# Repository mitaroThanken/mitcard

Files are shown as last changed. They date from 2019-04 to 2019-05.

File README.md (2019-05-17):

# mitcard

自作キーボードの習作。

## 特徴

* [Teency LC](https://www.pjrc.com/teensy/teensyLC.html)/[Teency 3.2](https://www.pjrc.com/teensy/teensy31.html)両対応
* 2x2のキーマトリックス
* [スイッチ用PCBソケット](https://yushakobo.jp/shop/a01ps/)使用
* 2つのタッチキー
* [modulo](http://biacco42.hatenablog.com/entry/2018/12/13/063814) 互換のジャック (※1)
* [SparkFun TeencyView](https://www.sparkfun.com/products/14048) 搭載可能 (※2)
* その他I/Oピンを外出し (※2)

※1 ソフトウェアは未対応、また、Teency LCは5Vトレラントではないことに注意。
※2 一部ピンが重複しています。

## 基板以外の材料

### 必須

* [Teency LC](https://www.pjrc.com/teensy/teensyLC.html)、または、[Teency 3.2](https://www.pjrc.com/teensy/teensy31.html)
  どちらかを用意してください。Modulo Pendant 互換を目指す場合は[Teency 3.2](https://www.pjrc.com/teensy/teensy31.html)一択です。
* ピンヘッダ・ピンソケット
  ボード内側のピンは使用していません。ですので、ボードの縁にあるスルーホールの数に対応したピンヘッダ・ピンソケットを用意してください。
  [スイッチサイエンス取扱のSparkFun製のもの](https://www.switch-science.com/catalog/2851/)とピンソケットでもよいです。

## メカニカルキーボードにするのに必須

以下のものをそれぞれ4つ用意してください。

* [スイッチ用PCBソケット](https://yushakobo.jp/shop/a01ps/)使用
* キースイッチ
  MX互換とKailh Chocに対応します。お好きなものをどうぞ。

## Modulo Pendant 互換品にするのに必須

以下のものをそれぞれ2つ用意してください。

* [MJ-4PP-9](http://akizukidenshi.com/catalog/g/gC-06070/)
* 抵抗
  (抵抗の大きさについては現在検討中。)

## OLED をつける場合

[SparkFun TeencyView](https://www.sparkfun.com/products/14048)が使用可能です。

ただし、D/Cを5ピンから21ピンに変更する必要があります。[ここ](https://learn.sparkfun.com/tutorials/teensyview-hookup-guide)を参考にデフォルトのラインを切って、21ピンの方にハンダでつなげてください。

(以降、更新予定)

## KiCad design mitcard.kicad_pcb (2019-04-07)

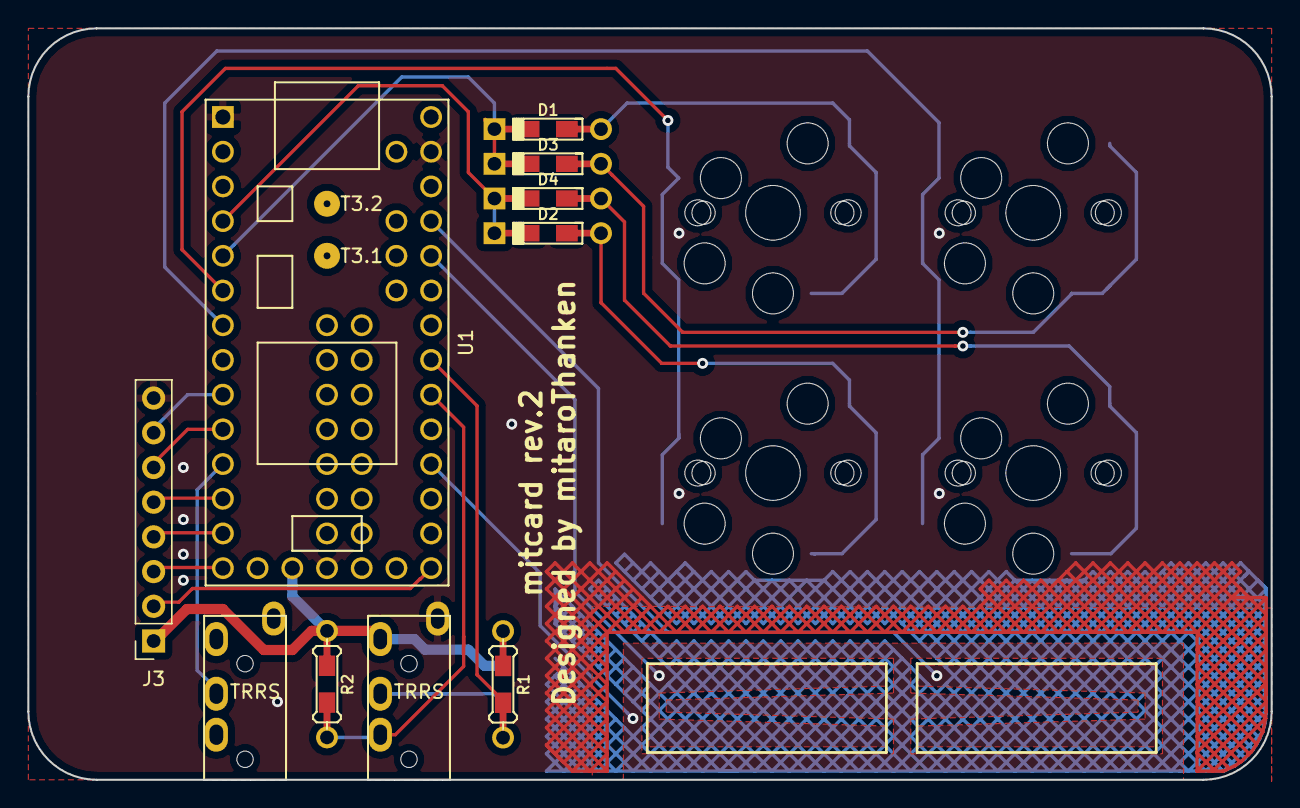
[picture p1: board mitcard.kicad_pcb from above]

Board: 2 copper layers, 91.0 x 55.0 mm, 14 parts (0 on the bottom side), 19 nets.

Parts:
D1, D2, D3, D4: D; Diode-dual
J1, J2: MJ-4PP-9; MJ-4PP-9_1side
J3: Conn_01x08; PinSocket_1x08_P2.54mm_Vertical
R1, R2: 4.7K; Resistor-Hybrid
SW1, SW2, SW3, SW4: SW_PUSH; CherryMX_Choc_Hotswap_1side
U1: Teensy-LC; Teensy30_31_32_LC

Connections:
/3.3V: J1.D, J3.1, R1.1, R2.1, U1.16
/INT: J2.C, U1.11
/SCL: J1.C, R1.2, U1.26
/SDA: J1.B, R2.2, U1.25
/col1row0: D3.2, SW3.2
CS: J3.5, U1.12
GND: J1.A, J3.8, U1.1, U1.17, U1.32
MISO: J3.3, U1.14
MOSI: J3.4, U1.13
unnamed: D1.2, SW1.2
unnamed: D2.2, SW2.2
unnamed: D4.2, SW4.2
RX: J3.7, U1.9
SCK: J3.2, U1.20
TX: J3.6, U1.10
col0: SW1.1, SW2.1, U1.6
col1: SW3.1, SW4.1, U1.7
row0: D1.1, D3.1, U1.5
row1: D2.1, D4.1, U1.4

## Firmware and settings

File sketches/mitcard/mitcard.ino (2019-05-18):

#include <TeensyView.h>
#include <Keyboard.h>
#include <Bounce2.h>

// for Keyswiches
const int ROW_NUM = 2;
const int COL_NUM = 2;
const int ROW_PIN[ROW_NUM] = { 3, 2 };
const int COL_PIN[COL_NUM] = { 4, 5 };

Bounce * debounce[ROW_NUM] = { new Bounce[COL_NUM], new Bounce[COL_NUM] };

const int KEY_MAP[ROW_NUM][COL_NUM] = {
  { KEY_A, KEY_B },
  { KEY_1, KEY_2 }
};

const String KEY_TITLE[ROW_NUM][COL_NUM] = {
  { "A?", "B!" },
  { "1.", "2.." }
};

// for Touch
const int TOUCH_B_PIN = 16;
const int TOUCH_L_PIN = 22;
const int TOUCH_R_PIN = 23;
const int TOUCH_DIFF = 500;

int touchB_avg = 0;
int touchR_avg = 0;
int touchL_avg = 0;
int touchB_th = 0;
int touchR_th = 0;
int touchL_th = 0;
bool touchB_touched = false;
bool touchL_touched = false;
bool touchR_touched = false;

void renew_touch_avg() {
  int t = touchRead(TOUCH_B_PIN);
  touchB_avg = (touchB_avg >> 1) + (touchB_avg >> 2) + (t >> 2);
  t = touchRead(TOUCH_L_PIN);
  touchL_avg = (touchL_avg >> 1) + (touchL_avg >> 2) + (t >> 2);
  t = touchRead(TOUCH_R_PIN);
  touchR_avg = (touchR_avg >> 1) + (touchR_avg >> 2) + (t >> 2);
}

// for LED
const int LED_PIN = 13;
int ledState = LOW;

// for TeensyView
// cf. https://learn.sparkfun.com/tutorials/teensyview-hookup-guide
#define PIN_RESET 15
#define PIN_DC    21
#define PIN_CS    10
#define PIN_SCK   13
#define PIN_MOSI  11

TeensyView oled(PIN_RESET, PIN_DC, PIN_CS, PIN_SCK, PIN_MOSI);
elapsedMillis sincePrint;

const String MY_NAME = "mitarothanken";
const String THIS_CARD = "mitcard!";

// Center and print a small title
// This function is quick and dirty. Only works for titles one
// line long.
void printTitle(String title, int font)
{
  int middleX = oled.getLCDWidth() / 2;
  int middleY = oled.getLCDHeight() / 2;

  oled.clear(PAGE);
  oled.setFontType(font);
  // Try to set the cursor in the middle of the screen
  oled.setCursor(middleX - (oled.getFontWidth() * (title.length() / 2)),
                 middleY - (oled.getFontWidth() / 2));
  // Print the title:
  oled.print(title);
  oled.display();
  //delay(1500);
  //oled.clear(PAGE);
  sincePrint = 0;
}

void setup(void) {
  // LED
  pinMode(LED_PIN, OUTPUT);
  digitalWrite(LED_PIN, ledState);

  // TeencyView (splash screen)
  oled.begin();
  oled.clear(ALL);
  oled.display();

  // Keyswitches (matrix)
  for (int row = 0; row < ROW_NUM; row++) {
    pinMode(ROW_PIN[row], OUTPUT);
  }

  for (int col = 0; col < COL_NUM; col++) {
    pinMode(COL_PIN[col], INPUT_PULLUP);
  }

  for (int row = 0; row < ROW_NUM; row++) {
    for (int col = 0; col < COL_NUM; col++) {
      debounce[row][col].attach(COL_PIN[col]);
      debounce[row][col].interval(25);
    }
    digitalWrite(ROW_PIN[row], HIGH);
  }

  // Touch (init)
  int i = 0;
  int t = 0;
  for (; i < 4; i++) {
    t = touchRead(TOUCH_B_PIN);
    touchB_avg += (t >> 2);
    t = touchRead(TOUCH_L_PIN);
    touchL_avg += (t >> 2);
    t = touchRead(TOUCH_R_PIN);
    touchR_avg += (t >> 2);
  }
  for (; i < 100; i++) {
    renew_touch_avg();
  }

  // FIXME TOUCH_DIFF
  touchB_th = touchB_avg + (TOUCH_DIFF >> 2);
  touchL_th = touchL_avg + TOUCH_DIFF;
  touchR_th = touchR_avg + TOUCH_DIFF;

  // Random seed.
  randomSeed(A0);

  // for Debug
  Serial.begin(9600);

  // Keyboard begin.
  Keyboard.begin();

  // TeencyView (clear)
  sincePrint = 0;
}

int delaycount = 0;
bool needToToggleLed = true;

void scanKeyswitches(void) {
  for (int row = 0; row < ROW_NUM; row++) {
    digitalWrite(ROW_PIN[row], LOW);

    for (int col = 0; col < COL_NUM; col++) {
      debounce[row][col].update();
      if (debounce[row][col].fell()) {
        printTitle(KEY_TITLE[row][col], 1);
        Serial.print("[");
        Serial.print(row);
        Serial.print(", ");
        Serial.print(col);
        Serial.print("] ");
        Serial.println("Pushed.");
        Keyboard.press(KEY_MAP[row][col]);
        needToToggleLed = true;
      } else if (debounce[row][col].rose()) {
        Serial.print("[");
        Serial.print(row);
        Serial.print(", ");
        Serial.print(col);
        Serial.print("] ");
        Serial.println("released.");
        Keyboard.release(KEY_MAP[row][col]);
        needToToggleLed = true;
      }
      if (needToToggleLed) {
        ledState = !ledState;
        digitalWrite(LED_PIN, ledState);
        needToToggleLed = false;
      }
    }
    digitalWrite(ROW_PIN[row], HIGH);
  }
}

void scanTouches(void) {
  renew_touch_avg();
  if (touchL_avg > touchL_th) {
    if ((!touchL_touched) && (touchB_avg > touchB_th)) {
      touchL_touched = true;
      Serial.println("L Touched.");
      Keyboard.print(MY_NAME);
      printTitle(MY_NAME, 0);
    }
  } else if (touchL_touched) {
    Serial.println("L released.");
    touchL_touched = false;
  }
  if (touchR_avg > touchR_th) {
    if ((!touchR_touched) && (touchB_avg > touchB_th)) {
      touchR_touched = true;
      Serial.println("R Touched.");
      Keyboard.print(THIS_CARD);
      printTitle(THIS_CARD, 1);
    }
  } else if (touchR_touched) {
    Serial.println("R released.");
    touchR_touched = false;
  }
}

const int oledInterval = 5000;

void oledClearOrDemo(void) {
  if (sincePrint > oledInterval * 6) {
    oled.clear(PAGE);
    oled.display();
    sincePrint = 0;
  } else if (sincePrint > oledInterval * 5) {
    for (int i = 0; i < 64; i++) {
      oled.pixel(random(oled.getLCDWidth()), random(oled.getLCDHeight()), WHITE, XOR);
    }
    oled.display();
  } else if (sincePrint > oledInterval * 4) {
    oled.clear(PAGE);
    oled.setFontType(1);
    oled.setCursor(0,0);
    oled.print("Touch");
    oled.setCursor(0, oled.getFontHeight());
    oled.print("white squares.");
    oled.display();
  } else if (sincePrint > oledInterval * 3) {
    oled.clear(PAGE);
    oled.setFontType(0);
    oled.setCursor(0, oled.getFontHeight());
    oled.print("https://github.com/");
    oled.setCursor(0, oled.getFontHeight() * 2);
    oled.print("mitaroThanken/mitcard");
    oled.display();
  } else if (sincePrint > oledInterval * 2) {
    int y = 0;
    oled.clear(PAGE);
    oled.setFontType(1);
    oled.setCursor(0,y);
    oled.print("mitcard");
    y += oled.getFontHeight();
    oled.setCursor(0, y);
    oled.setFontType(0);
    oled.print("designed by");
    y += oled.getFontHeight();
    oled.setCursor(0, y);
    oled.print("mitaroThanken.");
    oled.display();
  } else if (sincePrint > oledInterval) {
    oled.clear(PAGE);
    oled.setFontType(1);    // Set font to type 1
    oled.setCursor(73, 17); // move cursor
    oled.print("world!");   // Write a byte out as a character
    oled.setFontType(0);    // Set font to type 0
    oled.setCursor(67, 12); // move cursor
    oled.print("Hello");    // Write a byte out as a character
    oled.display();
  }
}

void loop(void) {
  scanKeyswitches();
  scanTouches();
  oledClearOrDemo();
}

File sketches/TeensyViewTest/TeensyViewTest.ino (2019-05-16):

/******************************************************************************
   TeensyView_Demo.ino
   SFE_TeensyView Library Demo
   Jim Lindblom @ SparkFun Electronics
   Original Creation Date: October 27, 2014
   Modified Febuary 2, 2017

   This sketch uses the TeensyView library to draw a 3-D projected
   cube, and rotate it along all three axes.

   Development environment specifics:
   Arduino IDE 1.6.12 w/ Teensyduino 1.31
   Arduino IDE 1.8.1 w/ Teensyduino 1.35
   TeensyView v1.0

   This code is beerware; if you see me (or any other SparkFun employee) at the
   local, and you've found our code helpful, please buy us a round!

   Distributed as-is; no warranty is given.
 ******************************************************************************/
#include <TeensyView.h>  // Include the SFE_TeensyView library

///////////////////////////////////
// TeensyView Object Declaration //
///////////////////////////////////
//Standard
#define PIN_RESET 15
//#define PIN_DC    5
#define PIN_CS    10
#define PIN_SCK   13
#define PIN_MOSI  11

//Alternate (Audio)
//#define PIN_RESET 2
#define PIN_DC    21
//#define PIN_CS    20
//#define PIN_SCK   14
//#define PIN_MOSI  7


TeensyView oled(PIN_RESET, PIN_DC, PIN_CS, PIN_SCK, PIN_MOSI);

void setup()
{
  oled.begin();    // Initialize the OLED
  oled.clear(ALL); // Clear the display's internal memory
  oled.display();  // Display what's in the buffer (splashscreen)
  delay(1000);     // Delay 1000 ms
  oled.clear(PAGE); // Clear the buffer.

  randomSeed(analogRead(A0) + analogRead(A1));
}

void pixelExample()
{
  printTitle("Pixels", 1);

  for (int i = 0; i < 1024; i++)
  {
    oled.pixel(random(oled.getLCDWidth()), random(oled.getLCDHeight()));
    oled.display();
  }
}

void lineExample()
{
  int middleX = oled.getLCDWidth() / 2;
  int middleY = oled.getLCDHeight() / 2;
  int xEnd, yEnd;
  int lineWidth = min(middleX, middleY);

  printTitle("Lines!", 1);

  for (int i = 0; i < 3; i++)
  {
    for (int deg = 0; deg < 360; deg += 15)
    {
      xEnd = lineWidth * cos(deg * PI / 180.0);
      yEnd = lineWidth * sin(deg * PI / 180.0);

      oled.line(middleX, middleY, middleX + xEnd, middleY + yEnd);
      oled.display();
      delay(10);
    }
    for (int deg = 0; deg < 360; deg += 15)
    {
      xEnd = lineWidth * cos(deg * PI / 180.0);
      yEnd = lineWidth * sin(deg * PI / 180.0);

      oled.line(middleX, middleY, middleX + xEnd, middleY + yEnd, BLACK, NORM);
      oled.display();
      delay(10);
    }
  }
}

void shapeExample()
{
  printTitle("Shapes!", 0);

  // Silly pong demo. It takes a lot of work to fake pong...
  int paddleW = 3;  // Paddle width
  int paddleH = 15;  // Paddle height
  // Paddle 0 (left) position coordinates
  int paddle0_Y = (oled.getLCDHeight() / 2) - (paddleH / 2);
  int paddle0_X = 2;
  // Paddle 1 (right) position coordinates
  int paddle1_Y = (oled.getLCDHeight() / 2) - (paddleH / 2);
  int paddle1_X = oled.getLCDWidth() - 3 - paddleW;
  int ball_rad = 2;  // Ball radius
  // Ball position coordinates
  int ball_X = paddle0_X + paddleW + ball_rad;
  int ball_Y = random(1 + ball_rad, oled.getLCDHeight() - ball_rad);//paddle0_Y + ball_rad;
  int ballVelocityX = 1;  // Ball left/right velocity
  int ballVelocityY = 1;  // Ball up/down velocity
  int paddle0Velocity = -1;  // Paddle 0 velocity
  int paddle1Velocity = 1;  // Paddle 1 velocity

  //while(ball_X >= paddle0_X + paddleW - 1)
  while ((ball_X - ball_rad > 1) &&
         (ball_X + ball_rad < oled.getLCDWidth() - 2))
  {
    // Increment ball's position
    ball_X += ballVelocityX;
    ball_Y += ballVelocityY;
    // Check if the ball is colliding with the left paddle
    if (ball_X - ball_rad < paddle0_X + paddleW)
    {
      // Check if ball is within paddle's height
      if ((ball_Y > paddle0_Y) && (ball_Y < paddle0_Y + paddleH))
      {
        ball_X++;  // Move ball over one to the right
        ballVelocityX = -ballVelocityX; // Change velocity
      }
    }
    // Check if the ball hit the right paddle
    if (ball_X + ball_rad > paddle1_X)
    {
      // Check if ball is within paddle's height
      if ((ball_Y > paddle1_Y) && (ball_Y < paddle1_Y + paddleH))
      {
        ball_X--;  // Move ball over one to the left
        ballVelocityX = -ballVelocityX; // change velocity
      }
    }
    // Check if the ball hit the top or bottom
    if ((ball_Y <= ball_rad) || (ball_Y >= (oled.getLCDHeight() - ball_rad - 1)))
    {
      // Change up/down velocity direction
      ballVelocityY = -ballVelocityY;
    }
    // Move the paddles up and down
    paddle0_Y += paddle0Velocity;
    paddle1_Y += paddle1Velocity;
    // Change paddle 0's direction if it hit top/bottom
    if ((paddle0_Y <= 1) || (paddle0_Y > oled.getLCDHeight() - 2 - paddleH))
    {
      paddle0Velocity = -paddle0Velocity;
    }
    // Change paddle 1's direction if it hit top/bottom
    if ((paddle1_Y <= 1) || (paddle1_Y > oled.getLCDHeight() - 2 - paddleH))
    {
      paddle1Velocity = -paddle1Velocity;
    }

    // Draw the Pong Field
    oled.clear(PAGE);  // Clear the page
    // Draw an outline of the screen:
    oled.rect(0, 0, oled.getLCDWidth() - 1, oled.getLCDHeight());
    // Draw the center line
    oled.rectFill(oled.getLCDWidth() / 2 - 1, 0, 2, oled.getLCDHeight());
    // Draw the Paddles:
    oled.rectFill(paddle0_X, paddle0_Y, paddleW, paddleH);
    oled.rectFill(paddle1_X, paddle1_Y, paddleW, paddleH);
    // Draw the ball:
    oled.circle(ball_X, ball_Y, ball_rad);
    // Actually draw everything on the screen:
    oled.display();
    delay(25);  // Delay for visibility
  }
  delay(1000);
}
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

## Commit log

2019-03-17 Create project.
    [Keyboard.kicad_pcb, Keyboard.sch]
2019-03-17 Add https://github.com/XenGi/teensy*
    * https://github.com/XenGi/teensy_library
    * https://github.com/XenGi/teensy.pretty
2019-03-18 テンプレートからの作成直後
    [mitcard.kicad_pcb, mitcard.sch]
2019-03-18 [wip] とりあえず配置
    キースイッチ、左側に持ってきたほうがいいかもしれない。
    [mitcard.kicad_pcb, mitcard.sch]
2019-03-21 タッチセンサー部を除いて仮配線完了？
    [mitcard.kicad_pcb, mitcard.sch]
2019-03-21 INT ピン変更
    [mitcard.kicad_pcb, mitcard.sch]
2019-03-21 SPI と I2C を引っ張り出しておく
    [mitcard.kicad_pcb, mitcard.sch]
2019-03-21 タッチパッド部も書いた
    [mitcard.kicad_pcb, mitcard.sch]
2019-03-25 ガーバーデータ出力
    [mitcard-B.Cu.gbl, mitcard-B.Cu.gbr, mitcard-B.Mask.gbr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]
2019-03-30 出来上がった基板の写真を追加
2019-03-30 動作確認用スケッチ
    Teensyduino 使用。
2019-04-06 foostan/kbd をフォークしたリポジトリを参照するように変更
2019-04-06 キースイッチのソケット、片面のみのフットプリントが入っているブランチに切り替え
2019-04-06 足の置き場を確保
    [mitcard.kicad_pcb, mitcard.sch]
2019-04-07 gvr 出力
    [mitcard-B.Cu.gbl, mitcard-B.Cu.gbr, mitcard-B.Mask.gbr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]
2019-05-04 スイッチのテストとタッチのテストを一本化
2019-05-16 TeencyView のテストコードを追加
    cf. https://learn.sparkfun.com/tutorials/teensyview-hookup-guide
2019-05-16 サンプルコードを統合
2019-05-17 Update README.md
    テンプレートのREADME.mdをmitcardのREADMEに書き換え開始。
2019-05-18 meishi展展示バージョン
